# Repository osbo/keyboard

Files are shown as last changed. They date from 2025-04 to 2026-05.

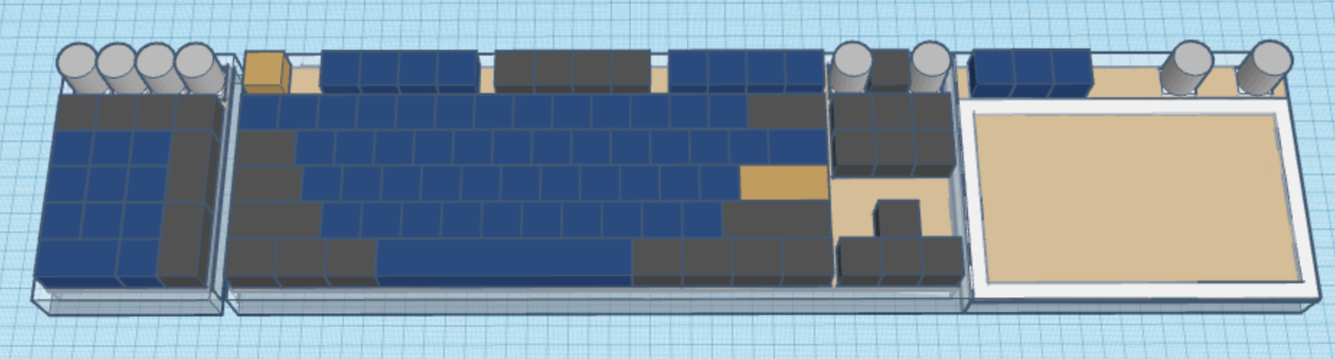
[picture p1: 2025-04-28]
3D design Copy of Handwired Keyboard Tinkercad.png

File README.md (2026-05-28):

# Handwired Keyboard

A wireless, modular handwired mechanical keyboard with a laser-cut bent-acrylic chassis, integrated trackpad, and rotary encoders wired into the switch matrix.

Render 1

## Hardware

The body is a single sheet of acrylic, cut on a laser cutter and heat-bent into the keyboard's compound angle. The switch matrix is handwired with 16 AWG enameled copper magnet wire — heavy enough that the matrix lines double as structural support behind the plate. Magnetic-pogo connectors latch the numpad, trackpad, and battery modules to the main board, so they hot-swap without re-pairing the host.

Rotary encoders share columns with regular switches by exploiting matrix scan timing: an encoder's two phases are wired to adjacent rows of the same column, and the firmware reads phase transitions inside the normal scan cycle. The result is full encoder support without burning extra GPIO. Guitar-style detented knobs supply the tactile resolution.

The trackpad is a custom dual-axis resistive panel, read through the MCU's ADC and integrated to a relative pointer in firmware.

## Modules

- **Main** — alpha block + thumb cluster, handwired matrix
- **Numpad** — detachable, magnetically aligned, joins the same composite USB HID device
- **Trackpad** — dual-axis resistive panel, pogo-connected
- **Battery** — wireless power, hot-swappable

## Software

Firmware is built on **QMK**, customized for the encoder-in-matrix scan and the resistive-trackpad analog frontend. The host sees a single composite HID device regardless of which modules are attached.

## Files

- `SVGs/` — laser-cut paths for the main plate, numpad plate, trackpad plate, fasteners, and feet
- `Final Renders.blend` — Blender file for the renders above
- `Handwired Keyboard.xlsx` — bill of materials

Render 2
Render 3

## License

MIT — see [LICENSE](LICENSE).

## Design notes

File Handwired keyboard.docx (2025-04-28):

Switches:

Kailh sample pack on nk

Zelios? Holy pandas? Blueberry?

I want a very tactile ~65g switch with little stem wiggle

Novelkeys plate mount stabs

Keycaps:

GMK blue samurai is an option, but really expensive

Case:

Ponoko clear acrylic

Plate:

2 piece brass plate

http://www.keyboard-layout-editor.com/#/

http://builder.swillkb.com/ and a bottom ring

Ponoko, https://www.laserboost.com/keyboards, or https://www.bigbluesaw.com/, comes down to price and material.

Wire:

A lot of 16 gauge enameled copper wire, straightened

Some Light wire

Small wire cutters

Electronics:

Teensy++ 2.0

1n4148 diodes

220 ohm resistors

White simple square leds

https://www.adafruit.com/product/682

Spst toggle switch

Spring-loaded pins: https://www.mill-max.com/products/check-stock?partnumber=8382201630001101

https://www.mill-max.com/products/check-stock?partnumber=8362201030001101

https://www.mill-max.com/products/check-stock?partnumber=8321002030004000

https://www.mill-max.com/products/check-stock?partnumber=8301001030004000

Usb mini b pretty cable

screws

standoffs

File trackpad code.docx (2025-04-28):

// define the pins im using

#define x2 A0

#define y1 A1

#define x1 A2

#define y2 A3

// add libraries

#include "Mouse.h"

// initialize variables

int x = 0;

int y = 0;

int z1 = 0;

int z2 = 0;

int pressed = 0;

int posbuffer[8];

int posbufferadj[8];

int startpos[2];

int changebuffer[8];

int xadj = 0;

int yadj = 0;

int badjumpsize = 10;

int tomove[2];

int sens = 3;

void setup()

{

// setup whatever i need to setup

Serial.begin(9600);

Mouse.begin();

}

void loop()

{

// grab the x position

pinMode(y1,INPUT);

pinMode(y2,INPUT);

digitalWrite(y2,LOW);

pinMode(x1,OUTPUT);

digitalWrite(x1,HIGH);

pinMode(x2,OUTPUT);

digitalWrite(x2,LOW);

// y = analogRead(y1);

y = analogRead(y1) * -1;

// grab the y position

pinMode(x1,INPUT);

pinMode(x2,INPUT);

digitalWrite(x2,LOW);

pinMode(y1,OUTPUT);

digitalWrite(y1,HIGH);

pinMode(y2,OUTPUT);

digitalWrite(y2,LOW);

// x = analogRead(x1) * -1;

x = analogRead(x1);

// find pressure

pinMode(y1,OUTPUT);

digitalWrite(y1,HIGH);

pinMode(x2,OUTPUT);

digitalWrite(x2,LOW);

pinMode(x1,INPUT);

pinMode(y2,INPUT);

z1 = analogRead(x1);

z2 = analogRead(y2);

if (z2 != 1023)

{

pressed = true;

}

else

{

pressed = false;

x = 0;

y = 0;

}

// continue the buffer

posbuffer[7] = posbuffer[5];

posbuffer[6] = posbuffer[4];

posbuffer[5] = posbuffer[3];

posbuffer[4] = posbuffer[2];

posbuffer[3] = posbuffer[1];

posbuffer[2] = posbuffer[0];

posbuffer[1] = y;

posbuffer[0] = x;

// adjust x and y

xadj = (posbuffer[0]+posbuffer[2]+posbuffer[4]+posbuffer[6])/4;

yadj = (posbuffer[1]+posbuffer[3]+posbuffer[5]+posbuffer[7])/4;

posbufferadj[7] = posbufferadj[5];

posbufferadj[6] = posbufferadj[4];

posbufferadj[5] = posbufferadj[3];

posbufferadj[4] = posbufferadj[2];

posbufferadj[3] = posbufferadj[1];

posbufferadj[2] = posbufferadj[0];

posbufferadj[1] = yadj;

posbufferadj[0] = xadj;

// touching me?

if (pressed)

{

// first touch?

if (posbuffer[2] == 0)

{

startpos[0] = x;

startpos[1] = y;

}

// continued touchy

else

{

// move along the change buffer

changebuffer[7] = changebuffer[5];

changebuffer[6] = changebuffer[4];

changebuffer[5] = changebuffer[3];

changebuffer[4] = changebuffer[2];

changebuffer[3] = changebuffer[1];

changebuffer[2] = changebuffer[0];

changebuffer[1] = posbufferadj[1] - posbufferadj[3];

changebuffer[0] = posbufferadj[0] - posbufferadj[2];

// remove de baddies

if (changebuffer[0] > badjumpsize or changebuffer[0] < badjumpsize*-1)

{

changebuffer[0] = 0;

}

if (changebuffer[1] > badjumpsize or changebuffer[2] < badjumpsize*-1)

{

changebuffer[1] = 0;

}

tomove[0] = changebuffer[0]*2;

tomove[1] = changebuffer[1]*2;

}

}

else

{

changebuffer[7] = changebuffer[5];

changebuffer[6] = changebuffer[4];

changebuffer[5] = changebuffer[3];

changebuffer[4] = changebuffer[2];

changebuffer[3] = changebuffer[1];

changebuffer[2] = changebuffer[0];

if (changebuffer[1] < 0)

{

changebuffer[1] + 10;

if (changebuffer[1] > 0)

{

changebuffer[1] = 0;

}

}

else

{

changebuffer[1] - 10;

if (changebuffer[1] < 0)

{

changebuffer[1] = 0;

}

}

if (changebuffer[0] < 0)

{

changebuffer[0] + 10;

if (changebuffer[0] > 0)

{

changebuffer[0] = 0;

}

}

else

{

changebuffer[0] - 10;

if (changebuffer[0] < 0)

{

changebuffer[0] = 0;

}

}

tomove[0] = changebuffer[0];

tomove[1] = changebuffer[1];

}

// put outs

Mouse.move(tomove[0] * sens, tomove[1] * sens);

// polling rate

delay(2);

// delay(1000);

}

// define the pins im using

#define x2 A0

#define y1 A1

#define x1 A2

#define y2 A3

// add libraries

#include "Mouse.h"

// initialize variables

int x = 0;

int y = 0;

int z1 = 0;

int z2 = 0;

int pressed = 0;

int posbuffer[8];

int posbufferadj[8];

int startpos[2];

int changebuffer[8];

int xadj = 0;

int yadj = 0;

int badjumpsize = 10;

int tomove[2];

float sens = 3.5;

float mouseaccel = 1;

int pressuresens = 110;

void setup()

{

// setup whatever i need to setup

Serial.begin(9600);

Mouse.begin();

}

void loop()

{

// grab the x position

pinMode(y1,INPUT);

pinMode(y2,INPUT);

digitalWrite(y2,LOW);

pinMode(x1,OUTPUT);

digitalWrite(x1,HIGH);

pinMode(x2,OUTPUT);

digitalWrite(x2,LOW);

// y = analogRead(y1);

y = analogRead(y1) * -1;

// grab the y position

pinMode(x1,INPUT);

pinMode(x2,INPUT);

digitalWrite(x2,LOW);

pinMode(y1,OUTPUT);

digitalWrite(y1,HIGH);

pinMode(y2,OUTPUT);

digitalWrite(y2,LOW);

// x = analogRead(x1) * -1;

x = analogRead(x1);

// find pressure

pinMode(y1,OUTPUT);

digitalWrite(y1,HIGH);

pinMode(x2,OUTPUT);

digitalWrite(x2,LOW);

pinMode(x1,INPUT);

pinMode(y2,INPUT);

z1 = analogRead(x1);

z2 = analogRead(y2);

if (z1 > pressuresens)

{

pressed = true;

}

else

{

pressed = false;

x = 0;

y = 0;

}

// continue the buffer

posbuffer[7] = posbuffer[5];

posbuffer[6] = posbuffer[4];

posbuffer[5] = posbuffer[3];

posbuffer[4] = posbuffer[2];

posbuffer[3] = posbuffer[1];

posbuffer[2] = posbuffer[0];

posbuffer[1] = y;

posbuffer[0] = x;

// adjust x and y

// xadj = (posbuffer[0]+posbuffer[2]+posbuffer[4]+posbuffer[6])/4;

// yadj = (posbuffer[1]+posbuffer[3]+posbuffer[5]+posbuffer[7])/4;

posbufferadj[7] = posbufferadj[5];

posbufferadj[6] = posbufferadj[4];

posbufferadj[5] = posbufferadj[3];

posbufferadj[4] = posbufferadj[2];

posbufferadj[3] = posbufferadj[1];

posbufferadj[2] = posbufferadj[0];

// posbufferadj[1] = yadj;

// posbufferadj[0] = xadj;

posbufferadj[1] = y;

posbufferadj[0] = x;

// touching me?

if (pressed)

{

// first touch?

if (posbuffer[2] == 0)

{

startpos[0] = x;

startpos[1] = y;

}

// continued touchy

else

{

// move along the change buffer

changebuffer[7] = changebuffer[5];

changebuffer[6] = changebuffer[4];

changebuffer[5] = changebuffer[3];

changebuffer[4] = changebuffer[2];

changebuffer[3] = changebuffer[1];

changebuffer[2] = changebuffer[0];

changebuffer[1] = posbufferadj[1] - posbufferadj[3];

changebuffer[0] = posbufferadj[0] - posbufferadj[2];

// remove de baddies

if (changebuffer[0] > badjumpsize or changebuffer[0] < badjumpsize*-1)

{

changebuffer[0] = 0;

}

if (changebuffer[1] > badjumpsize or changebuffer[2] < badjumpsize*-1)

{

changebuffer[1] = 0;

}

if (changebuffer[0] < 0)

{

tomove[0] = pow((changebuffer[0] * -1),mouseaccel) * -1;

}

else

{

tomove[0] = pow(changebuffer[0],mouseaccel);

}

if (changebuffer[1] < 0)

{

tomove[1] = pow((changebuffer[1] * -1),mouseaccel) * -1;

}

else

{

tomove[1] = pow(changebuffer[1],mouseaccel);

}

}

}

else

{

changebuffer[7] = changebuffer[5];

changebuffer[6] = changebuffer[4];

changebuffer[5] = changebuffer[3];

changebuffer[4] = changebuffer[2];

changebuffer[3] = changebuffer[1];

changebuffer[2] = changebuffer[0];

if (changebuffer[1] < 0)

{

changebuffer[1] + 10;

if (changebuffer[1] > 0)

{

changebuffer[1] = 0;

}

}

else

{

changebuffer[1] - 10;

if (changebuffer[1] < 0)

{

changebuffer[1] = 0;

}

}

if (changebuffer[0] < 0)

{

changebuffer[0] + 10;

if (changebuffer[0] > 0)

{

changebuffer[0] = 0;

}

}

else

{

changebuffer[0] - 10;

if (changebuffer[0] < 0)

{

changebuffer[0] = 0;

}

}

// tomove[0] = changebuffer[0];

// tomove[1] = changebuffer[1];

tomove[0] = 0;

tomove[1] = 0;

}

// put outs

Mouse.move(tomove[0] * sens, tomove[1] * sens);

// Serial.print(z1);

// Serial.print(", ");

// Serial.print(z2);

// Serial.print("\n");

// polling rate

delay(1);

// delay(1000);

}

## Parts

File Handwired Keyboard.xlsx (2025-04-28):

 | Product | Price | Ship date | Link
Switches | Glorious Pandas | 75 |  | https://www.pcgamingrace.com/products/glorious-panda-mechanical-switches
Caps | Novelkeys WoB | 50 | dont know | https://novelkeys.xyz/collections/keycaps/products/cherry-pbt-white-on-black
Case | TAP Platics, Lakeside |  | quick, local | https://www.tapplastics.com/product/plastics/cut_to_size_plastic/acrylic_sheets_clear/508 | https://www.tapplastics.com/product/plastics/cut_to_size_plastic/satinice_clear/656
Plate | Ponoko, standard aluminum 1.6mm | 70 | not too slow | https://www.ponoko.com/materials/standard-aluminum
Stabs | Cherry Stabs | 16.25 | out of stock | https://novelkeys.xyz/collections/miscellaneous/products/cherry-stabilizers?variant=3747939057704
Lube | Tribosys 3204 | 9 | quick | https://www.1upkeyboards.com/shop/parts-and-tools/lubricant/switch-lubricant-2ml/
Microcontroller | Teensy++ 2.0 | 30 | quick | https://www.amazon.com/PJRC-Teensy-2-0/dp/B00NC4302Q
Diodes | 1n4148 diodes | 8 |  | https://www.amazon.com/McIgIcM-1n4148-switching-Standard-Through/dp/B06XB1R2NK
Encoder | EC11 encoder | 10 | quick | https://www.amazon.com/DIYhz-Rotary-Encoder-Digital-Potentiometer/dp/B07D3DF8TK
Knobs | Chrome Guitar Knob | 40 | not too slow | https://www.amazon.com/Vintage-Forge-Telecaster-Precision-BK30US-CHR/dp/B07NKSQVFV
Wire | Enameled Copper wire, 16 and 34 AWG | 16 | quick | https://www.amazon.com/BNTECHGO-AWG-Magnet-Wire-Transformers/dp/B07H7FTRG5 | https://www.amazon.com/BNTECHGO-AWG-Magnet-Wire-Transformers/dp/B07J9Z9WX7
Hardware | 20x5mm and screw | 15 | not too slow | https://www.amazon.com/300pcs-Standoff-Column-Spacer-Assortment/dp/B07B9X1KY6 | https://www.amazon.com/TUOREN-Stainless-Steel-Washers-200Pcs/dp/B07RFFMXTS
Switch opener and lube station | A bunch of keyboard tools | 23 | not too slow | https://www.amazon.com/Acrylic-Station-Platform-Mechanical-Keyboard/dp/B08H5PQWR5
Calipers | Adoric Digital Caliper, 0-6 inch | 10.5 | quick | https://www.amazon.com/Digital-Caliper-Adoric-Calipers-Measuring/dp/B07DFFYCXS
Wood Caps | Esc and enter | 13 | wasn't great | https://kbdfans.com/collections/keycaps/products/oem-wasd?variant=6868121944122
Hot Swap Sockets | Kailh Hot Swap Sockets | 21 | quick | https://www.amazon.com/Hot-swappable-Socket-CPG151101S11-Mechanical-Keyboard/dp/B07K8CCMQZ
Cable | DIY | 31 | quick | https://kprepublic.com/products/v2-coiled-cable-wire-mechanical-keyboard-gh60-usb-cable-mini-micro-type-c-usb-port-for-poker-2-xd64-xd75-xd96-mobile-phone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 | https://cruzctrl.gg/collections/diy-cable-parts/products/aviator-connector-gx12 | https://zapcables.com/paracord/ | https://zapcables.com/techflex-double-sleeving/ | black with silver tracers and carbon
Wire Stripper | 10-22 vice grip wire stripper | 10 | quick | https://www.amazon.com/VISE-GRIP-Stripping-Cutter-8-Inch-2078309/dp/B000JNNWQ2?c=ts&ts_id=553398
Spring Pins | Mill-Max 0906-4-15-20-75-14-11-0 | 12 | quick | https://www.digikey.com/en/products/detail/mill-max-manufacturing-corp/0906-4-15-20-75-14-11-0/1147052
Contacts | Mill-Max 1969-0-00-15-00-00-03-0 | 14 | quick | https://www.mouser.com/ProductDetail/Mill-Max/1969-0-00-15-00-00-03-0
Magnets | 15x6x3mm | 9 | not too slow | https://www.amazon.com/15x6x3mm-Retangle-Multi-use-Refrigerator-Projects/dp/B07QJ6YPM7
Touchscreen | Resistive Touchscreen Overlay - 7" diag. 165mm x 105mm - 4 Wire | 15 | quick | https://www.adafruit.com/product/1676
Usb touchscreen controller | Resistive Touch Screen to USB Mouse Controller - AR1100 | 10 | quick | https://www.adafruit.com/product/1580
Usb hub | Zero4U - 4-Port USB Hub without Pogo Pins - v1.3 | 7 | quick | https://www.adafruit.com/product/4115
Internal usb cords | Usb A to micro B and usb male a to female a | 17 | not too slow | https://www.amazon.com/AmazonBasics-USB-2-0-Cable-Male/dp/B00NH13S44 | https://www.amazon.com/SaiTech-Pack-15cm-Adjustable-Extension/dp/B01GA1GKYW?c=ts&s=pc&ts_id=464394
Usb to bluetooth adapter | Bluetooth Adapter for Keyboard & Mouse (BT-500) | 35 | stocks december 1 | http://handheldsci.com/kb/
Battery | 5000mAh Battery | 20 | quick | https://www.anker.com/products/variant/powercore-5000/A1109011
Mouse Feet | Hotline Games G502 Competition Feet, Corepad MX Master 3 Feet | 20 | long | https://www.itaktech.com/products/copy-of-hotline-games-logitech-g502-mouse-feet?variant=19082258481221 | https://www.corepad.de/en/Corepad-Skatez-Logitech-Teflon-Mousefeet-Mouse-Feet-Hyperglides-Hyperglide/Corepad-Skatez-Logitech-MX-Master-3.html
Webcam | C922 | 120 | quick | https://www.logitech.com/en-us/products/webcams/c922-pro-stream-webcam.960-001087.html
Total: | 339.25 | 726.75
 |  |  |  |  | Product | Link | 1102.87 | Delivery Date
Features: |  |  |  |  | Test pieces of plastic |  | 1 | 2021-01-15
Glorious pandas with trybosis 3203 |  |  |  |  | Standoffs | https://www.amazon.com/300pcs-Standoff-Column-Spacer-Assortment/dp/B07B9X1KY6 | 9.99 | 2021-01-21
Cherry plate mount stabs with trybosis 3203 and dialectric grease |  |  |  |  | Calipers | https://www.amazon.com/Digital-Caliper-Adoric-Calipers-Measuring/dp/B07DFFYCXS | 11.55 | 2021-01-28
GMK Wob |  |  |  |  | Ponoko Test 1 | https://www.ponoko.com/account/orders/1062833 | 22.38 | 2021-02-15
Guitar knobs |  |  |  |  | Ponoko Test 2 | https://www.ponoko.com/account/orders/1062959 | 3.84 | 2021-02-16
TKL |  |  |  |  | Magnets, Battery, Encoders, Knobs 1 | https://www.amazon.com/15x6x3mm-Retangle-Multi-use-Refrigerator-Projects/dp/B07QJ6YPM7 https://www.amazon.com/Anker-PowerCore-Ultra-Compact-High-Speed-Technology/dp/B01CU1EC6Y https://www.amazon.com/DIYhz-Rotary-Encoder-Digital-Potentiometer/dp/B07D3DF8TK https://www.amazon.com/Vintage-Forge-Telecaster-Precision-BK30US-CHR/dp/B07NKSQVFV | 60.43 | 2021-02-09
Removable numpad |  |  |  |  | Usb Hub, Touchscreen, Mouse Controller | http://www.adafruit.com/product/4115, http://www.adafruit.com/product/1676, http://www.adafruit.com/product/1580 | 49.16 | 2021-02-12
Removable trackpad |  |  |  |  | Spring pins | https://www.digikey.com/en/products/detail/mill-max-manufacturing-corp/0906-4-15-20-75-14-11-0/1147052 | 22.33 | 2021-02-05
Removable wireless module with big battery |  |  |  |  | Contacts | https://www.mouser.com/ProductDetail/Mill-Max/1969-0-00-15-00-00-03-0 | 33.82 | 2021-02-04
2-7 encoders |  |  |  |  | Amazon |  | 145.56 | 2021-02-19
Hardline handwired |  |  |  |  | Glorious | https://www.pcgamingrace.com/products/glorious-panda-mechanical-switches | 82.96 | 2021-02-23
Hot-swap |  |  |  |  | 1upKeyboards | https://www.1upkeyboards.com/shop/parts-and-tools/lubricant/switch-lubricant-3ml/ | 19.8 | 2021-02-23
2 usb passthrough ports |  |  |  |  | KPRepublic |  | 11.9 | 2021-03-02
8.5 degree typing angle |  |  |  |  | Zap Cables | https://zapcables.com/techflex-double-sleeving/, https://zapcables.com/paracord/ | 11.85 | 2021-02-20
Wrist rests |  |  |  |  | Drop | https://drop.com/buy/gmk-white-on-black-custom-keycap-set | 121.11
Aluminum plate and other elements |  |  |  |  | Handheld Scientific (I paid) | http://handheldsci.com/kb/ | 40.95 | 2021-02-20
Walnut top layer |  |  |  |  | KBDFans (I paid) | https://kprepublic.com/products/v2-coiled-cable-wire-mechanical-keyboard-gh60-usb-cable-mini-micro-type-c-usb-port-for-poker-2-xd64-xd75-xd96-mobile-phone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 | 31.98 | 2021-02-22
Leaf spring mount |  |  |  |  | Adafruit | https://www.adafruit.com/product/334, https://www.adafruit.com/product/1571, https://www.adafruit.com/product/3677 | 30 | 2021-03-06
Aviator out |  |  |  |  | Aliexpress | https://www.aliexpress.com/item/4000704860840.html?spm=a2g0o.cart.0.0.19f83c00hlwdAS&mp=1 | 4.15 | 2021-03-22
 |  |  |  |  | Divinikey | https://divinikey.com/products/durock-plate-mount-stabilizers | 17.57 | 2021-03-05
 |  |  |  |  | Amazon | https://www.amazon.com/Vintage-Forge-Telecaster-Precision-BK30US-CHR/dp/B07NKSQVFV https://www.amazon.com/UGREEN-Braided-Charger-Charging-Controller/dp/B01NCJE1RE https://www.amazon.com/Knurled-Screws-Shoulder-Stainless-Metric/dp/B01N4AIYKV (https://www.amazon.com/Hxchen-Female-Connector-GX12-6P-Aviation/dp/B07V54KP4D) | 71.28 | 2021-03-24
 |  |  |  |  | Ponoko | https://www.ponoko.com/account/orders/1067229 | 274.11 | 2021-03-27
 |  |  |  |  | Ponoko | https://www.ponoko.com/account/orders/1068337 | 2.25 | 2021-03-27
 |  |  |  |  | Amazon | https://www.amazon.com/15x6x3mm-Retangle-Multi-use-Refrigerator-Projects/dp/B07QJ6YPM7 | 9.9 | 2021-03-29
 |  |  |  |  | Adafruit | http://www.adafruit.com/product/4115 | 13

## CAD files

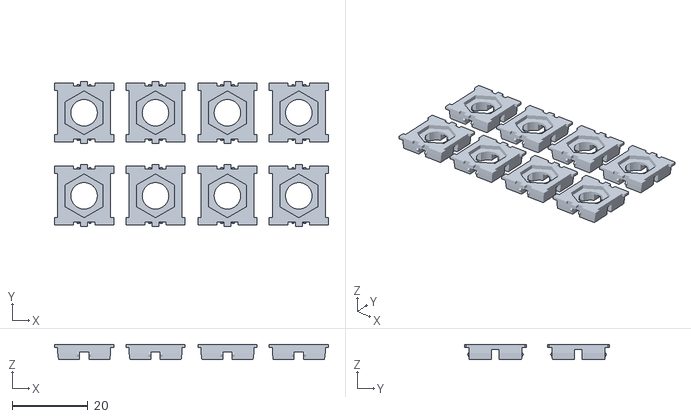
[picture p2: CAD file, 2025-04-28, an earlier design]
SVGs/v4/Encoder Adapters.stl
72.2 x 38.2 x 4.00

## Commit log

2026-05-28 Rewrite README in consistent project style
    Drop emoji headers, marketing tone, Contributing / "represents an achievement"
    sections. Ground hardware/firmware description in actual file layout.
2026-05-28 Use American English (enamelled → enameled, customised → customized)
